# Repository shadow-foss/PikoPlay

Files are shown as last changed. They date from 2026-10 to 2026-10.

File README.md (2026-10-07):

# PikoPlay

A small open-source handheld game console built on the RP2040. This repo has the firmware and a
3D-printable case. The PCB design files will be added later.

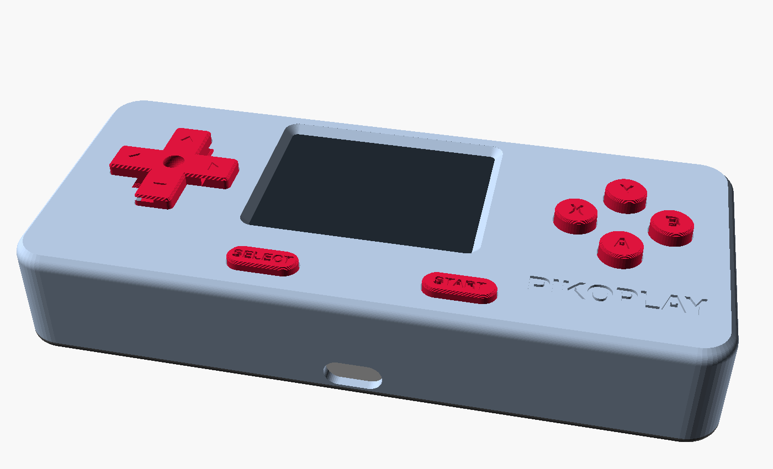
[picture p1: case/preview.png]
PikoPlay case


What it plays:

* Built-in games: Pong (1 or 2 players), Snake, Flappy, Breakout
* NEKO, a little cat you look after
* Game Boy, Game Boy Color, NES and Atari 2600 games (homebrew, or dumps of carts you own)

It can also act as a USB gamepad for a PC. There is no sound (no speaker on the board).

## Hardware

* GD007-Glyph-RP2040 module (RP2040, 8 MB flash, USB-C), running at 250 MHz
* 2.0" ILI9225 SPI screen, 176x220, used sideways as 220x176
* 10x 6 x 6 mm tactile switches (5 mm plunger): D-pad, A B X Y, START, SELECT
* LiPo battery 34 x 50 x 7 mm with a 2-pin JST plug, and a small power switch
* Buttons connect their GPIO to GND (internal pull-ups, no resistors). The screen uses SPI0.

| Pin | GPIO | | Button | GPIO |
|---|---|---|---|---|
| SCK / MOSI | 2 / 3 | | UP / DOWN | 7 / 8 |
| LCD CS / DC / RST | 4 / 5 / 6 | | LEFT / RIGHT | 12 / 13 |
| SD CS / MISO | 1 / 0 | | A / B | 25 / 26 |
| | | | X / Y | 24 / 23 |
| | | | START / SELECT | 21 / 20 |

## Install the firmware

Install [PlatformIO](https://platformio.org/), plug the console in over USB and run:

```sh
pio run -t upload
```

## Use it

* LEFT/RIGHT picks a system, A opens it, B goes back. Only A starts things.
* Hold SELECT+START for one second to leave a game. Saves are written then.
* SETTINGS has the theme, screen size, menu speed and more.

## Add games

Games are copied over USB while the console is on, with `pikolink`. It works on Linux, macOS and
Windows and finds the console by itself. Build it with any C++ compiler:
`c++ -std=c++17 -O2 -Isrc tools/pikolink.cpp -o pikolink` (or `make -C tools`).

```sh
pikolink put game.gb  /roms/gb/game.gb
pikolink put game.gbc /roms/gbc/game.gbc
pikolink put game.nes /roms/nes/game.nes
pikolink put game.a26 /roms/atari/game.a26
pikolink ls /roms/gb
pikolink rm /roms/gb/game.gb
pikolink get /saves/gbc/game.sav backup.sav   # back up a save
```

Games go to a 7.25 MB area of flash that the firmware update does not touch, so they and your
saves survive firmware updates. PlatformIO's `uploadfs` would erase the saves, so use `pikolink`.
Only use ROMs you are allowed to: homebrew or dumps of your own cartridges.

## Make your own built-in game

Games are plain C++ in `src/native/`. Look at `arcade.cpp` (Pong, Snake, Flappy, Breakout): each
game reads the buttons once per frame, draws the screen and calls `presentDiff()`. Add yours to
`Arcade::Game` and it shows up in the ARCADE list.

## Print the case

Print everything from `case/stl/` (PLA or PETG, no supports): `shell`, `lid`, `dpad`, `startsel`,
and either `abxy` or the four `button_*` files to give each face button its own colour.

Screws and inserts:

* PCB to shell: 4x M2.5 x 5 screws into 4x M2.5 x 5 brass heat-set inserts
* Lid to shell: 4x M3 x 8 screws into 4x M3 x 5 brass heat-set inserts

Battery: a 34 x 50 x 7 mm LiPo.

To change the model, open `case/pikocase.scad` in OpenSCAD; all sizes are in `case/config.scad`.

## License

* Software: MIT ([LICENSE](LICENSE))
* Case: CERN-OHL-P-2.0 ([case/LICENSE](case/LICENSE))
* Game Boy core: Walnut-CGB (MIT), in `lib/walnut_cgb/`.
* NES core: InfoNES / pico-infones (GPL-3.0), in `lib/infones/` with its own
  [LICENSE](lib/infones/LICENSE). Because of it, a built firmware binary is covered by the GPL-3.0
  as a whole.
* Built with the Arduino-Pico core and TFT_eSPI (fetched by PlatformIO).

PikoPlay is a hobby project and is not connected to Nintendo or Atari. Game Boy and NES are
trademarks of Nintendo, Atari 2600 of Atari; the names only say which games it can run.

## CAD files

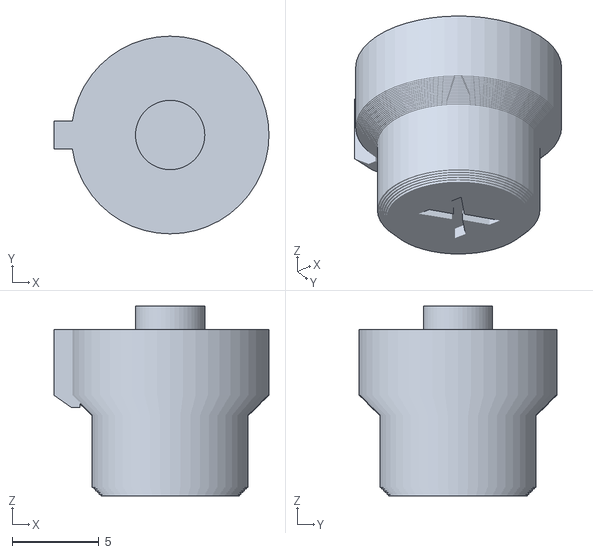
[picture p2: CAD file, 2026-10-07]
case/stl/button_X.stl
12.4 x 11.4 x 11.0

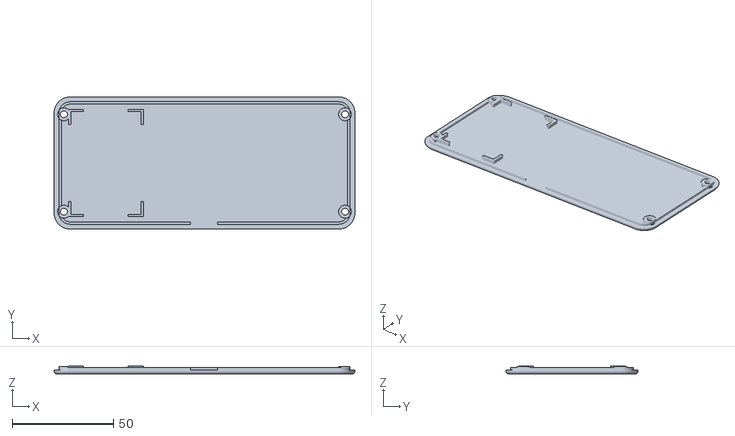
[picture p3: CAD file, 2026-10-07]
case/stl/lid.stl
148.4 x 65.2 x 3.79

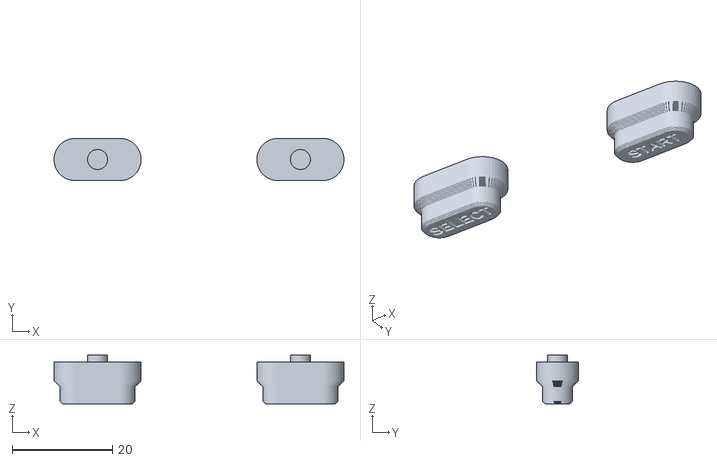
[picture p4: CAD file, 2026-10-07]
case/stl/startsel.stl
57.9 x 8.40 x 9.76

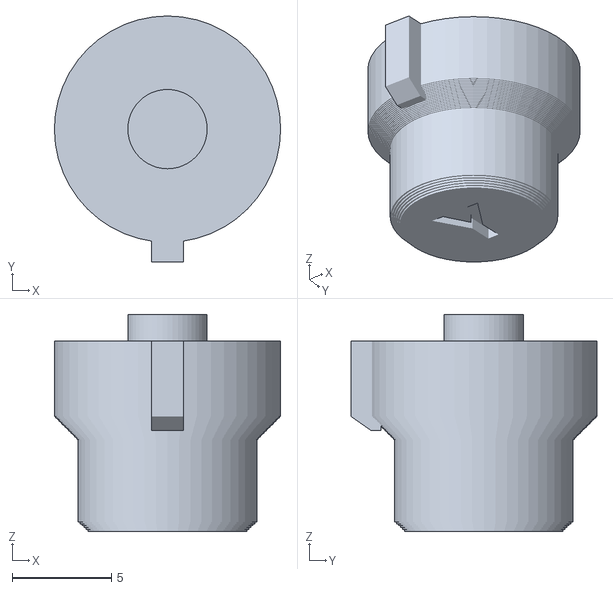
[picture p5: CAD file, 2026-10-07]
case/stl/button_Y.stl
11.4 x 12.4 x 11.0

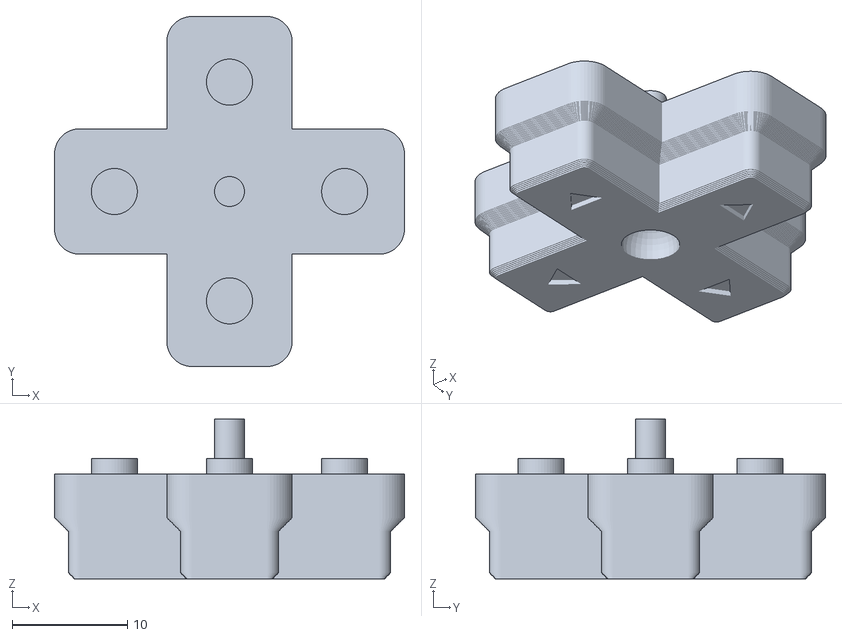
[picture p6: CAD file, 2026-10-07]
case/stl/dpad.stl
30.4 x 30.4 x 13.9

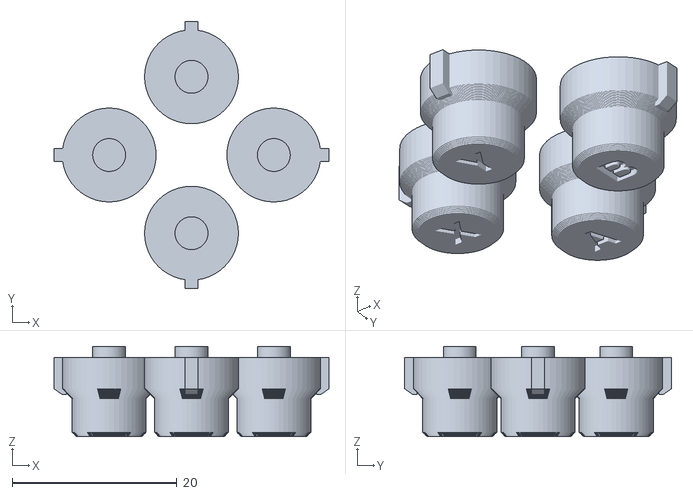
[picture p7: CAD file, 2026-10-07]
case/stl/abxy.stl
33.4 x 32.4 x 11.0

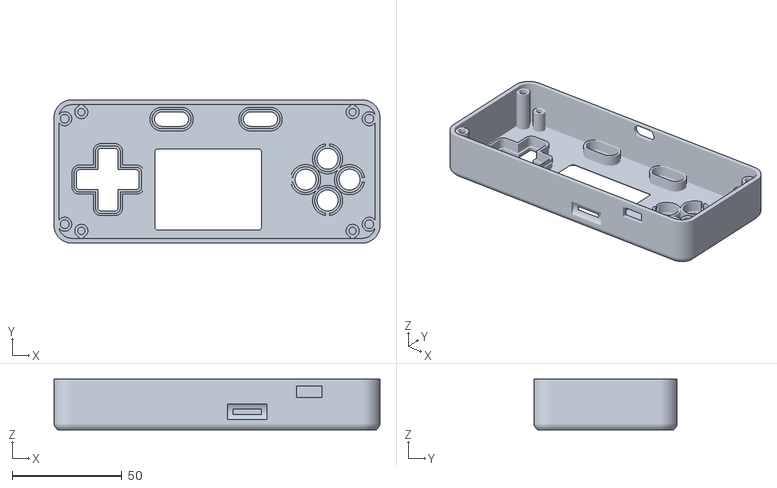
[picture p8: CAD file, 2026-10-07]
case/stl/shell.stl
148.4 x 65.2 x 23.1

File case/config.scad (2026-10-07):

// PikoPlay case: every measurement in one place (millimetres).
//
// Coordinates match the KiCad board: the origin is the centre of the 130 x 60 PCB, z = 0 is the
// middle of the PCB, +z points out of the front (screen side), +y is the top edge (microSD side).

$fn = 48;
eps = 0.01;

// ---- Tolerances
tol_lcd_z = 0.5;    // air above the screen glass
tol_btn_z = 0.05;   // button flange to front plate: the up/down play of every button
tol_sd    = 1.3;    // microSD slot: +/- this around the card
tol_sw    = 0.2;    // power switch hole, added per side

// ---- Main PCB
pcb_size  = [130, 60];
pcb_t     = 1.6;
pcb_top   = pcb_t / 2;
pcb_bot   = -pcb_t / 2;
pcb_clear = 0.4;    // PCB edge to case wall
pcb_holes = [[-61.75, 27], [61.75, 27], [-61.75, -27], [61.75, -27]];   // M2.5

// ---- Buttons on the PCB (6 x 6 tactile switches)
btn_h     = 5.0;    // PCB top to the top of a switch plunger
btn_top_z = pcb_top + btn_h;
dpad_c    = [-49.656, 3.7];   // centre of the four d-pad switches
dpad_sw   = [[0, 9.5], [0, -9.5], [-10, 0], [10, 0]];   // relative to dpad_c
abxy      = [[40.344, 3.7], [60.344, 3.7], [50.344, 13.2], [50.344, -5.8]];   // X B Y A
startsel  = [[-20.7, -23.844], [19.8, -23.844]];                              // SELECT START

// ---- Boards mounted on headers
lcd_pcb_h = 6.5;    // main PCB top to the top of the display module's PCB
mcu_pcb_h = 4.5;    // main PCB back to the outside of the RP2040 module
mcu_pcb_t = 1.55;
lcd_lift  = lcd_pcb_h - 4.35;
mcu_drop  = (mcu_pcb_h - mcu_pcb_t) - 0.28;
mcu_low_z = -6.91 - mcu_drop;   // lowest part on the RP2040 module

// ---- Screen (2.0" ILI9225, landscape)
lcd_top_z   = 7.97 + lcd_lift;   // top of the glass
lcd_aa      = [39.6, 31.68];     // visible area
lcd_aa_c    = [-4.04, 8.17];     // its centre
lcd_open    = [52, 40.5];        // screen opening
lcd_open_r  = 3;

// ---- Openings
usb_c    = [-0.18, -4.3 - mcu_drop];   // USB-C centre [x, z]
usb_cut  = [12.4, 6.2];
sd_x     = [7.2, 20.2];                // microSD slot
sd_z     = [2.0 + lcd_lift - tol_sd, 2.0 + lcd_lift + tol_sd];
sd_scoop = 5;                          // finger scoop radius
sw_x     = 42;                         // power switch hole (top edge)
sw_hole  = [11, 5];
sw_z     = -4.9;

// ---- Case body
wall        = 2.2;
front_t     = 1.8;
z_fi        = lcd_top_z + tol_lcd_z;   // inside of the front plate
z_front     = z_fi + front_t;          // outside of the front plate
z_split     = min(-10.6, mcu_low_z - 0.5, usb_c[1] - usb_cut[1]/2 - 0.6);   // shell / lid joint
lid_t       = 1.8;
z_back      = z_split - lid_t;
front_round = 3.0;
back_round  = 1.5;
cav_half    = [72.0, pcb_size[1]/2 + pcb_clear];   // inside, half size
out_half    = cav_half + [wall, wall];             // outside, half size
out_r       = 8;
cav_r       = out_r - wall;

// ---- Lid fit
lip_h   = 1.4;
lip_t   = 1.2;
lip_gap = 0.2;

// ---- Lid screws: 4x M3 x 8 from the back into M3 x 5 heat-set inserts
m3_screw_l  = 8;
m3_head     = "cap";      // "cap" (counterbored) or "csk" (countersunk)
m3_head_d   = 6.2;
m3_cbore    = 2.0;
m3_insert_d = 4.0;
m3_insert_l = 5;
m3_clear_d  = 3.4;
m3_boss_d   = m3_insert_d + 2.4;
m3_pos_x    = 66.1 + m3_boss_d/2;
m3_pos      = [for (sx = [-1, 1], sy = [-1, 1]) [sx * m3_pos_x, sy * 24]];
lid_boss_h  = 2.0;
z_meet      = z_split + lid_boss_h;   // where the lid bosses meet the shell columns
m3_seat_z   = m3_head == "cap" ? z_back + m3_cbore : z_back;
m3_tip_z    = m3_seat_z + m3_screw_l;

// ---- PCB screws: 4x M2.5 x 5 from the back of the PCB into M2.5 x 5 heat-set inserts
m25_insert_d = 3.3;
m25_insert_l = 5;
m25_boss_d   = 6.0;

// ---- Battery (LiPo 34 x 50 x 7), held by corner ribs on the lid
bat_size  = [34, 50];
bat_t     = 7;
bat_pos   = [-48.6, 0];
bat_rib_h = 2.0;

// ---- Button caps
btn_clear    = 0.25;   // cap body to front plate hole, per side
sleeve_clear = 0.18;   // cap flange to guide sleeve, per side
sleeve_len   = 5;
sleeve_wall  = 1.0;
flange_w     = 1.2;
cap_bot      = btn_top_z + 0.02;
btn_stem     = 2.1 - 0.7 - 0.05;   // post from the cap down to the switch plunger
btn_stem_d   = 4.0;
flange_top   = z_fi - tol_btn_z + btn_clear;
flange_stop  = flange_top - btn_clear;
abxy_d       = 9;
pill         = [15, 6];      // START / SELECT
dpad_arm     = [28, 8.5];    // d-pad span and arm width
cap_top      = z_front + 3.0;   // ABXY top
dpad_top     = z_front + 2.5;
ss_top       = z_front + 1.8;   // START / SELECT top

// Anti-rotation tab on each ABXY cap, riding in a slot in its sleeve
abxy_key_dir = [180, 0, 90, 270];
key_w        = 1.6;
key_l        = 1.0;
key_clear    = 0.18;

// Keep the button sleeves away from the display module
lcd_keepout = [[[-33.9, -13.36, 0], [33.9, 29.7, 5.5 + lcd_lift]],
               [[-28.4, -12.2, 0], [26.45, 28.6, z_fi]]];

// ---- Text
font        = "DejaVu Sans:style=Bold";
logo_text   = "PIKOPLAY";
logo_size   = 5.212;           // about 35 mm wide
logo_pos    = [50.344, -19];   // right side, under the ABXY buttons
abxy_labels = ["X", "B", "Y", "A"];
abxy_label_size = 3.514;
ss_labels   = ["SELECT", "START"];
ss_label_size   = 2.352;
text_depth  = 0.6;

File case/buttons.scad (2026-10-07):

// Button caps. They are modelled where they sit in the case; to_bed() flips them for printing.

include <config.scad>
include <shapes.scad>

// Generic cap from a 2D outline (the child): body with a 0.5 mm top chamfer, and a retaining
// flange under the front plate with a 45 degree top so it prints without supports.
// The chamfers are built from thin offset steps so concave outlines (the d-pad cross) work too.
module cap(top_z) {
    n = 5;
    translate([0, 0, cap_bot]) linear_extrude(top_z - cap_bot - 0.5 + eps) children(0);
    for (i = [1:n]) translate([0, 0, top_z - 0.5 + (i - 1) * 0.5 / n])
        linear_extrude(0.5 / n + eps) offset(delta = -i * 0.5 / n) children(0);
    translate([0, 0, cap_bot]) linear_extrude(flange_top - flange_w - cap_bot + eps) offset(delta = flange_w) children(0);
    for (i = [1:4 * n]) translate([0, 0, flange_top - flange_w + (i - 1) * flange_w / (4 * n)])
        linear_extrude(flange_w / (4 * n) + eps) offset(delta = flange_w * (1 - i / (4 * n))) children(0);
}

// Post from the underside of a cap down to its switch.
module stem() {
    translate([0, 0, cap_bot - btn_stem]) cylinder(d = btn_stem_d, h = btn_stem + eps);
}

// Tab on the flange of a round cap that stops it from turning.
module abxy_key() {
    r0 = abxy_d / 2 + flange_w;
    hull() {
        translate([r0 - 0.5, -key_w / 2, cap_bot]) cube([key_l + 0.5, key_w, flange_top - flange_w - cap_bot]);
        translate([r0 - 0.5, -key_w / 2, min(flange_top - flange_w + key_l, flange_stop - 0.25) - eps]) cube([0.5, key_w, eps]);
    }
}

// One of the four face buttons (0 X, 1 B, 2 Y, 3 A), with its letter engraved on top.
module abxy_button(i) {
    translate(abxy[i]) difference() {
        union() {
            cap(cap_top) circle(d = abxy_d);
            rotate(abxy_key_dir[i]) abxy_key();
            stem();
        }
        translate([0, 0, cap_top - text_depth]) linear_extrude(1)
            text(abxy_labels[i], size = abxy_label_size, font = font, halign = "center", valign = "center");
    }
}

module abxy_buttons() {
    for (i = [0:len(abxy) - 1]) abxy_button(i);
}

module startsel_buttons() {
    for (i = [0:len(startsel) - 1]) translate(startsel[i]) difference() {
        union() {
            cap(ss_top) pill2d(pill);
            stem();
        }
        translate([0, 0, ss_top - text_depth]) linear_extrude(1)
            text(ss_labels[i], size = ss_label_size, font = font, halign = "center", valign = "center");
    }
}

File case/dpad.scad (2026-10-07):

// One-piece d-pad: rocks on a centre pin, with a post over each of its four switches.

include <config.scad>
include <shapes.scad>
use <buttons.scad>

module dpad() {
    translate(dpad_c) {
        difference() {
            cap(dpad_top) dpad2d();
            // arrow dimples
            for (a = [0:90:270]) rotate(a) translate([dpad_arm[0] / 2 - 4.5, 0, dpad_top - 0.4])
                linear_extrude(1) polygon([[1.2, 0], [-1, 1.6], [-1, -1.6]]);
            // centre dimple
            translate([0, 0, dpad_top - 0.6]) sphere(d = 5, $fn = 32);
        }
        // pivot pin
        zcyl(2.6, pcb_top + 0.25, cap_bot + eps);
        // posts onto the switches
        for (p = dpad_sw) translate(p) stem();
    }
}

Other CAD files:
case/stl/button_A.stl
case/stl/button_B.stl
case/lid.scad
case/pikocase.scad
case/shapes.scad
case/shell.scad

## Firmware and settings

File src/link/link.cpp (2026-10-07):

#include "link/link.h"
#include <Arduino.h>
#include <stdio.h>
#include <string.h>
#include "util/crc32.h"

namespace {
constexpr uint8_t kMagic1 = 0xA5, kMagic2 = 0x5A;
constexpr uint32_t kFrameTimeoutUs = 200000;
enum Cmd : uint8_t { HELLO = 1, LIST, READ, WRITE_BEGIN, WRITE_DATA, WRITE_END, DELETE_, MKDIR, LAUNCH = 0x0B };
enum Err : uint8_t { E_REQ = 1, E_PATH, E_NOTFOUND, E_BUSY, E_STORAGE, E_ORDER, E_CRC, E_NOFS };
const char* kFw = "PIKOPLAY 0.5";

uint32_t rd32(const uint8_t* p) { return (uint32_t)p[0] | ((uint32_t)p[1] << 8) | ((uint32_t)p[2] << 16) | ((uint32_t)p[3] << 24); }
uint16_t rd16(const uint8_t* p) { return (uint16_t)(p[0] | (p[1] << 8)); }
void wr32(uint8_t* p, uint32_t v) { for (int i = 0; i < 4; ++i) p[i] = (uint8_t)(v >> (8 * i)); }

// Reads a `len u8, bytes` string; returns bytes consumed or 0 on error.
size_t getStr(const uint8_t* p, size_t n, char* out, size_t cap) {
  if (n < 1 || (size_t)p[0] + 1 > n || (size_t)p[0] >= cap) return 0;
  memcpy(out, p + 1, p[0]);
  out[p[0]] = 0;
  return (size_t)p[0] + 1;
}
}  // namespace

bool Link::pathOk(const char* p) {
  const size_t n = strlen(p);
  if (n < 2 || n > 63 || p[0] != '/') return false;
  for (size_t k = 0; k < n; ++k) if ((uint8_t)p[k] < 0x20 || (uint8_t)p[k] > 0x7E || p[k] == '\\') return false;
  // Components: none empty (no "//" or trailing '/'), none "." or "..".
  bool first = true, rootOk = false;
  size_t start = 1;
  for (size_t k = 1; k <= n; ++k) {
    if (k < n && p[k] != '/') continue;
    const size_t cl = k - start;
    if (cl == 0) return false;
    if (cl == 1 && p[start] == '.') return false;
    if (cl == 2 && p[start] == '.' && p[start + 1] == '.') return false;
    if (first) {
      static const char* const roots[] = {"roms", "saves"};
      for (const char* r : roots) if (strlen(r) == cl && !strncmp(p + start, r, cl)) rootOk = true;
      first = false;
    }
    start = k + 1;
  }
  return rootOk;
}

void Link::begin() {
  Serial.begin(115200);
}

int Link::sweepTemp(Storage& st) {
  static const char* const dirs[] = {"/roms/atari", "/roms/nes", "/roms/gb", "/roms/gbc", "/saves"};
  int removed = 0;
  for (const char* dir : dirs) {
    struct Found { char name[48]; bool sd; };
    struct Ctx { Found f[8]; int n; } ctx{};
    st.forEachEntry(dir, [](const char* name, uint32_t, bool isDir, bool onSd, void* v) {
      Ctx& c = *(Ctx*)v;
      const size_t l = strlen(name);
      if (isDir || l < 6 || l >= sizeof c.f[0].name || strcmp(name + l - 5, ".part") || c.n >= 8) return true;
      strcpy(c.f[c.n].name, name);
      c.f[c.n++].sd = onSd;
      return true;
    }, &ctx);
    for (int i = 0; i < ctx.n; ++i) {
      char path[96];
      snprintf(path, sizeof path, "%s/%s", dir, ctx.f[i].name);
      fs::FS* f = st.fsHolding(path);
      if (f && f->remove(path)) ++removed;
    }
  }
  return removed;
}

void Link::reply(uint8_t cmd, uint8_t seq, const uint8_t* p, size_t n) {
  uint8_t head[6] = {kMagic1, kMagic2, cmd, seq, (uint8_t)n, (uint8_t)(n >> 8)};
  uint32_t crc = 0xFFFFFFFFu;
  crc = piko::crc32Update(crc, head + 2, 4);
  crc = piko::crc32Update(crc, p, n);
  crc = ~crc;
  uint8_t tail[4];
  wr32(tail, crc);
  Serial.write(head, 6);
  if (n) Serial.write(p, n);
  Serial.write(tail, 4);
}

void Link::error(uint8_t seq, uint8_t code, const char* msg) {
  uint8_t b[40];
  b[0] = code;
  size_t n = strlen(msg);
  if (n > 38) n = 38;
  memcpy(b + 1, msg, n);
  reply(0xFF, seq, b, 1 + n);
}

void Link::abortUpload(Storage&) {
  if (!up_) return;
  if (upShelf_) {
    shelfUp_.abort();  // the space was never indexed: nothing to clean up
  } else {
    upFile_.close();
    if (upFs_) upFs_->remove(upTmp_);
  }
  up_ = false;
}

void Link::poll(uint64_t now, Storage& storage, bool busy) {
  if (state_ != kIdle && now - frameStartUs_ > kFrameTimeoutUs) state_ = kIdle;  // stalled frame
  for (int n = 0; n < 128 && Serial.available() > 0; ++n) feed((uint8_t)Serial.read(), now, storage, busy);
  // A game started mid-upload (someone pressed A on the handheld): uploads are refused while a
  // game runs, so abandon this one now and delete its temp file instead of leaving it behind.
  if (busy && up_) abortUpload(storage);
}

void Link::feed(uint8_t c, uint64_t now, Storage& storage, bool busy) {
  switch (state_) {
    case kIdle:
      if (c == kMagic1) { state_ = kSync2; frameStartUs_ = now; }
      return;
    case kSync2:
      if (c == kMagic2) { state_ = kHead; headN_ = 0; return; }
      state_ = kIdle;
      if (c == kMagic1) { state_ = kSync2; frameStartUs_ = now; return; }
      return;
    case kHead:
      head_[headN_++] = c;
      if (headN_ == 4) {
        len_ = rd16(head_ + 2);
        got_ = 0;
        if (len_ > kMaxPayload) { state_ = kIdle; return; }  // oversize: drop, resync
        state_ = len_ ? kBody : kCrc;
        crcN_ = 0;
      }
      return;
    case kBody:
      buf_[got_++] = c;
      if (got_ == len_) { state_ = kCrc; crcN_ = 0; }
      return;
    case kCrc:
      crc_[crcN_++] = c;
      if (crcN_ == 4) {
        state_ = kIdle;
        uint32_t crc = piko::crc32Update(0xFFFFFFFFu, head_, 4);
        crc = ~piko::crc32Update(crc, buf_, len_);
        if (crc == rd32(crc_)) handle(head_[0], head_[1], buf_, len_, storage, busy);
      }
      return;
  }
}
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

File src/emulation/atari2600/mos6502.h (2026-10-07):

#pragma once
#include <stdint.h>

// 6502 / 6507 CPU. Every bus access is one cycle (Bus::cycle()), so the video chip stays in step
// and instruction timing matches the real chip. Official opcodes plus the stable unofficial ones;
// KIL halts. BCD enables decimal mode.
//
// Bus: uint8_t read(uint16_t); void write(uint16_t, uint8_t); void cycle(); bool stalled();
template <class Bus, bool BCD>
class Mos6502 {
 public:
  enum : uint8_t { N = 0x80, V = 0x40, U = 0x20, B = 0x10, D = 0x08, I = 0x04, Z = 0x02, C = 0x01 };
  uint8_t a = 0, x = 0, y = 0, sp = 0xFD, p = U | I;
  uint16_t pc = 0;
  bool halted = false;
  uint32_t cycles = 0;

  explicit Mos6502(Bus& bus) : bus_(bus) {}

  void reset() {
    sp = 0xFD; p = U | I; halted = false; a = x = y = 0;
    const uint8_t lo = rd(0xFFFC), hi = rd(0xFFFD);
    pc = (uint16_t)(hi << 8 | lo);
  }

  void step() {
    if (bus_.stalled() || halted) { bus_.cycle(); ++cycles; return; }
    const uint8_t op = fetch();
    const uint8_t cc = op & 3, bbb = (op >> 2) & 7, aaa = op >> 5;
    if ((op & 0x1F) == 0x10) {  // branches
      const uint8_t f = (op >> 6) == 0 ? N : (op >> 6) == 1 ? V : (op >> 6) == 2 ? C : Z;
      branch(((p & f) != 0) == ((op & 0x20) != 0));
      return;
    }
    switch (op) {
      case 0x00: fetch(); interrupt(0xFFFE); return;  // BRK
      case 0x20: {  // JSR
        const uint8_t lo = fetch();
        rd((uint16_t)(0x100 | sp));
        push((uint8_t)(pc >> 8)); push((uint8_t)pc);
        const uint8_t hi = fetch();
        pc = (uint16_t)(hi << 8 | lo);
        return;
      }
      case 0x40: {  // RTI
        idle(); rd((uint16_t)(0x100 | sp));
        p = (uint8_t)((pull() & ~B) | U);
        const uint8_t lo = pull(), hi = pull();
        pc = (uint16_t)(hi << 8 | lo);
        return;
      }
      case 0x60: {  // RTS
        idle(); rd((uint16_t)(0x100 | sp));
        const uint8_t lo = pull(), hi = pull();
        pc = (uint16_t)(hi << 8 | lo);
        rd(pc); ++pc;
        return;
      }
      case 0x08: idle(); push(p | B | U); return;                                             // PHP
      case 0x28: idle(); rd((uint16_t)(0x100 | sp)); p = (uint8_t)((pull() & ~B) | U); return;  // PLP
      case 0x48: idle(); push(a); return;                                                      // PHA
      case 0x68: idle(); rd((uint16_t)(0x100 | sp)); a = pull(); nz(a); return;                // PLA
      case 0x4C: pc = fetch16(); return;                                                       // JMP abs
      case 0x6C: {  // JMP (ind), with the page-wrap bug
        const uint16_t ptr = fetch16();
        const uint8_t lo = rd(ptr), hi = rd((uint16_t)((ptr & 0xFF00) | ((ptr + 1) & 0xFF)));
        pc = (uint16_t)(hi << 8 | lo);
        return;
      }
      case 0x88: idle(); nz(--y); return;
      case 0xC8: idle(); nz(++y); return;
      case 0xCA: idle(); nz(--x); return;
      case 0xE8: idle(); nz(++x); return;
      case 0xA8: idle(); nz(y = a); return;
      case 0xAA: idle(); nz(x = a); return;
      case 0x98: idle(); nz(a = y); return;
      case 0x8A: idle(); nz(a = x); return;
      case 0xBA: idle(); nz(x = sp); return;
      case 0x9A: idle(); sp = x; return;
      case 0x18: idle(); p &= ~C; return;
      case 0x38: idle(); p |= C; return;
      case 0x58: idle(); p &= ~I; return;
      case 0x78: idle(); p |= I; return;
      case 0xB8: idle(); p &= ~V; return;
      case 0xD8: idle(); p &= ~D; return;
      case 0xF8: idle(); p |= D; return;
      case 0xEA: case 0x1A: case 0x3A: case 0x5A: case 0x7A: case 0xDA: case 0xFA: idle(); return;
      case 0x80: case 0x82: case 0x89: case 0xC2: case 0xE2: fetch(); return;
      case 0x04: case 0x44: case 0x64: readOperand(kZp); return;
      case 0x14: case 0x34: case 0x54: case 0x74: case 0xD4: case 0xF4: readOperand(kZpx); return;
      case 0x0C: readOperand(kAbs); return;
      case 0x1C: case 0x3C: case 0x5C: case 0x7C: case 0xDC: case 0xFC: readOperand(kAbx); return;
      case 0xEB: sbc(fetch()); return;
      case 0x02: case 0x12: case 0x22: case 0x32: case 0x42: case 0x52:
      case 0x62: case 0x72: case 0x92: case 0xB2: case 0xD2: case 0xF2: halted = true; return;
      default: break;
    }
    switch (cc) {
      case 1: {  // ORA AND EOR ADC STA LDA CMP SBC
        static const uint8_t kModes[8] = {kIzx, kZp, kImm, kAbs, kIzy, kZpx, kAby, kAbx};
        const uint8_t mode = kModes[bbb];
        if (aaa == 4) {
          if (mode == kImm) { readOperand(kImm); return; }
          wr(effAddr(mode, kWrite), a);
          return;
        }
        const uint8_t v = readOperand(mode);
        if (aaa == 5) { nz(a = v); return; }
        alu(aaa, v);
        return;
      }
      case 2: {  // ASL ROL LSR ROR STX LDX DEC INC
        if (bbb == 2 && aaa < 4) { idle(); a = rmwOp(aaa, a); return; }
        if (aaa == 4 || aaa == 5) {
          uint8_t mode;
          switch (bbb) {
            case 0: mode = kImm; break;
            case 1: mode = kZp; break;
            case 3: mode = kAbs; break;
            case 5: mode = kZpy; break;
            case 7: mode = kAby; break;
            default: return;
          }
          if (aaa == 4) {
            if (mode == kImm || mode == kAby) { readOperand(mode); return; }
            wr(effAddr(mode, kWrite), x);
            return;
          }
          nz(x = readOperand(mode));
          return;
        }
        uint8_t mode;
        switch (bbb) {
          case 1: mode = kZp; break;
          case 3: mode = kAbs; break;
          case 5: mode = kZpx; break;
          case 7: mode = kAbx; break;
          default: readOperand(kImm); return;
        }
        const uint16_t addr = effAddr(mode, kRmw);
        const uint8_t v = rd(addr);
        wr(addr, v);  // dummy write of the unmodified value
        wr(addr, rmwOp(aaa, v));
        return;
      }
      case 0: {  // BIT STY LDY CPY CPX
        uint8_t mode;
        switch (bbb) {
          case 0: mode = kImm; break;
          case 1: mode = kZp; break;
          case 3: mode = kAbs; break;
          case 5: mode = kZpx; break;
          case 7: mode = kAbx; break;
          default: return;
        }
        switch (aaa) {
          case 1: {  // BIT
            if (mode != kZp && mode != kAbs) { readOperand(mode); return; }
            const uint8_t v = readOperand(mode);
            p = (uint8_t)((p & ~(N | V | Z)) | (v & (N | V)) | ((v & a) ? 0 : Z));
            return;
          }
          case 4:  // STY
            if (mode == kImm || mode == kAbx) { readOperand(mode); return; }
            wr(effAddr(mode, kWrite), y);
            return;
          case 5: nz(y = readOperand(mode)); return;  // LDY
          case 6:
            if (mode == kZpx || mode == kAbx) { readOperand(mode); return; }
            cmp(y, readOperand(mode));
            return;
          case 7:
            if (mode == kZpx || mode == kAbx) { readOperand(mode); return; }
            cmp(x, readOperand(mode));
            return;
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
